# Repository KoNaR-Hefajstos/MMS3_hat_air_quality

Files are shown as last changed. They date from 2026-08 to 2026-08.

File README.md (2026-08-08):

# MMS3 Hat Air Quality
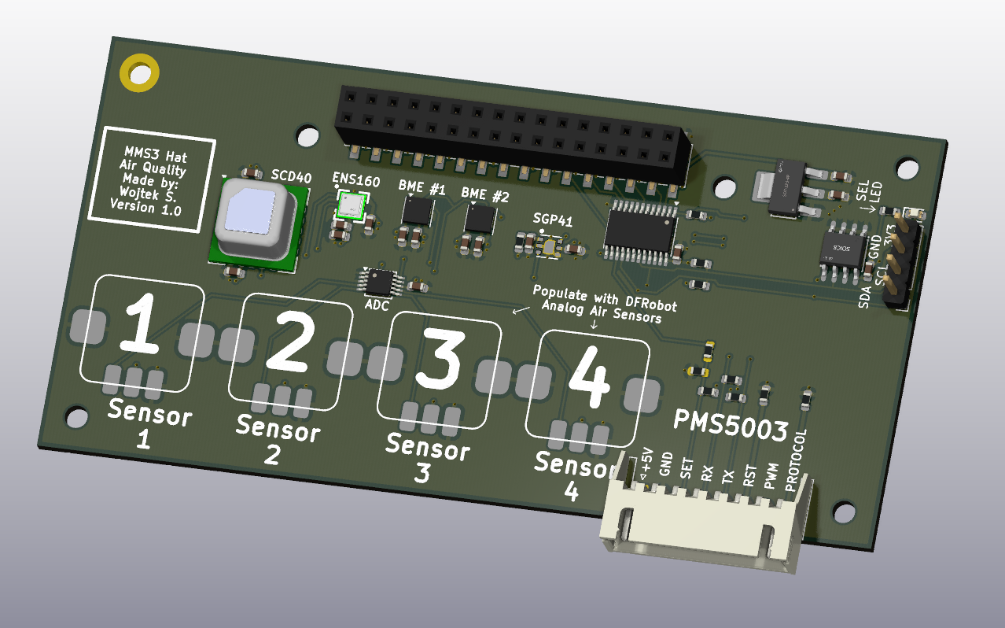
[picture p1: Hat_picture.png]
punkt 1


## Sekcja 1: Dokumentacja Hat'a

### Krótki opis projektu
Hat Air Quality to hat z miejscami na różne czujniki jakości powietrza. Są to 2x BME688 (lub kompatybilne) oraz po jednym PMS5003 (lub kompatybline), SCD40-D-R2, SGP41-D-R4, ENS160-BGLM oraz 4x miejsca na analogowe czujniki DFRobot (np. DFRobot SEN0564).

Dzięki temu potrafi mierzyć temperature, wilgotność, ciśnienie, VOC, IAQ, PM, CO2, NOX oraz wielkości mierzone przez 4x czujniki DFRobot

### Zgodność ze standardem ChainBus

* ✅ Używa złącza ChainBus, nie zmienia jego miejsca ani pinoutu.
* ✅ Używa wyłącznie interfejsów I2C, SPI lub UART i nie inicjuje samodzielnie nowych transmisji (Nie jest master'em I2C albo SPI).
* ✅ Spełnia wymagania mechaniczne standardu (wymiary PCB, rozstaw otworów).
* ❌ Pobiera maksymalny prąd zgodny z ilością na jednego hat'a **-> normalna praca >125mA, potrzeba określić empirycznie**
* ✅ Obsługuje napięcie wejściowe BRD_VIN do wartości 48V.

### Komunikacja i adresowanie

#### Adresacja I2C

| Układ (IC) | Funkcja | Address |
| :--- | :--- | :-----: |
| **BME688 #1** | Czujnik jakości powietrza | `0x76`  |
| **BME688 #2** | Czujnik jakości powietrza | `0x77`  |
| **SCD40-D-R2**  | Czujnik jakości powietrza | `0x62`  |
| **SGP41-D-R4**  | Czujnik jakości powietrza | `0x59`  |
| **ENS160-BGLM** | Czujnik jakości powietrza | `0x52`  |
| **ADS1115IDGS** | Przetwornik ADC | `0x48`  |

#### Magistrala SPI
Brak urządzeń, ale CS może być użyty do włączania/wyłączania PMS5003

#### Magistrala UART
UART jest podłączony bezpośrednio do PMS5003.

| Układ (IC)  | Funkcja | chainbus/multiplexer |
| :--- | :--- | :---: |
| **PMS5003** | Czujnik jakości powietrza | `chainbus` |

### Pinout złączy

| Jn | Co | Jaki pin co robi |
| :--- | :--- | :--- |
| **J101** | Złącze do PMS5003 | **Pin 1: +5V** <br>**Pin 2: GND**<br>**Pin 3: SET** – Wejście włączenia/uśpienia (Stan wysoki = normalna praca, Stan niski = tryb uśpienia)<br>**Pin 4: RX Czujnika**<br>**Pin 5: TX Czujnika** <br>**Pin 6: RST** – Reset modułu (aktywny stan niski - reset po podaniu GND)<br>**Pin 7: PWM** – Wyjście sygnału PWM, NC <br>**Pin 8: PROTOCOL** – Wybór protokołu/trybu pracy czujnika. Ma pulldown 10k |

### Konfiguracja układu (Zworki/Rezystory)

| Co | Jak podłączone | Efekt |
| :--- | :--- | :--- |
| **R101, R102, R104** | Wlutowany R104 | Pin SET zawsze wysoki |
| | Wlutowany  R101, R102 | Pin SET podłączony do pinu CS ChainBus |

### Szczegółowy opis techniczny
Czujniki BME688, SCD40-D-R2, SGP41-D-R4, ENS160-BGLM są bezpośrednio podłączone do magistrali I2C.

Czujniki analogowe DFRobot są podłączone do przetwornika ADC ADS1115IDGS. Kanały przetwornika 0-3 są podłączone do czujników 1-4.

 Czujnik PMS5003 jest bezpośrednio
podłączony do magistrali UART. Jego pin SEL domyślnie jest podciągany do +3.3V przez rezystor R104 (10k), ale można go wylutować
i wlutować R101 R102. Wtedy pin SEL jest bezpośrednio podłączony do pinu CS chainbus oraz ściągany (weak pulldown) do 0V przez R101 (10k).
Jeśli nie potrzebujesz oszczędzać prądu to zalecane jest zostawienie wlutowanego R104.

### Gotowe arkusze hierarchiczne
Brak

---

## Sekcja 2: Specyfikacja standardu ChainBus

### Architektura i łączenie modułów
Standard ChainBus umożliwia modułowe łączenie hatów. Na jednym MMS3 można zamontować pionowo **do 8 hat'ów**. Połączenie realizowane jest poprzez wpięcie złącza męskiego kolejnego hat'a w złącze żeńskie poprzedniego

### Komunikacja i sterowanie
Magistrala ChainBus jest w pełni cyfrowa. Płyta główna nie steruje bezpośrednio sygnałami ogólnego przeznaczenia (GPIO) na poszczególnych hat'ach. Wszelkie operacje (np. obsługa diod LED, odczyt krańcówek, generowanie sygnałów PWM) muszą być realizowane przez dedykowane układy scalone (np. ekspandery portów, sterowniki) komunikujące się przez interfejsy systemowe.

*Przykład:*
`MCU` $\rightarrow$ `Expander GPIO po I2C` $\rightarrow$ `Dioda LED`

Wybór aktywnego modułu realizowany jest przez układ przełącznika magistrali (bus switch) na płycie głównej. Dzięki temu linie I2C, SPI i UART są niezależne dla każdego hat'a (brak konfliktów adresów I2C między różnymi hatami).
* **Identyfikacja:** Każdy moduł powinien posiadać pamięć EEPROM na magistrali I2C w celu identyfikacji płyty przez system - układ M24C64-W skonfigurowany na adres `1010000` przy liniach adresowych A0, A1, A2 zwartych do masy.

### Zasilanie
Złącze ChainBus dostarcza następujące linie zasilania:

| Magistrala zasilania | Napięcie znamionowe | Maksymalny prąd (łączny dla 8 hatów) | Szacowany prąd na jeden hat |
| :--- | :---: | :---: | :---: |
| **5V** | 5.0 V | 1.0 A | 125 mA |
| **12V stby** | 12.0 V | 0.5 A | 65 mA |
| **BRD_VIN** | 12.0 V – 48.0 V | 1.5 A | 185 mA |

*   Komponenty podłączone do linii `BRD_VIN` muszą być przystosowane do pracy z napięciem od 12V do **48 V**.
*   W przypadku zapotrzebowania na wyższą moc, dopuszczalne jest zastosowanie dodatkowego złącza zasilania XT60 (obciążalność do ok. 60 A).

### Wymagania mechaniczne i złącza
* **Wymiary PCB:** Niedozwolona jest zmiana obrysu płytki oraz położenia otworów montażowych, aby zachować kompatybilność mechaniczną.
* **Pozycjonowanie złączy ChainBus:** Położenie złącza standardu 2x16 SMD (raster 2.54 mm) musi być zgodne z szablonem. Złącze żeńskie montowane jest na stronie FRONT, natomiast złącze męskie na stronie BACK.
* **Interfejsy zewnętrzne:** Złącza wejścia/wyjścia (domyślnie standard JST-XH 2.5 mm o obciążalności do 3 A) oraz opcjonalne złącze XT60 powinny być umieszczone przy dolnej krawędzi płytki. Elementy regulacyjne i sygnalizacyjne (potencjometry, przełączniki, diody LED) należy lokalizować przy prawej krawędzi płytki.
* **Komponenty** Wszystkie komponenty powinny być na stronie front płytki żeby nie haczyły o elementy ze wcześniejszego hat'a

---

## Sekcja 3: Licencja, linki i tagi

### Licencjonowanie projektu

*   **PCB:** CERN-OHL-P
*   **Software:** MIT License

[Template](https://github.com/KoNaR-Hefajstos/MMS3_hat_templates/) jest na licencji CC0 1.0 Universal. **Reszta projektu nie jest na tej licencji**

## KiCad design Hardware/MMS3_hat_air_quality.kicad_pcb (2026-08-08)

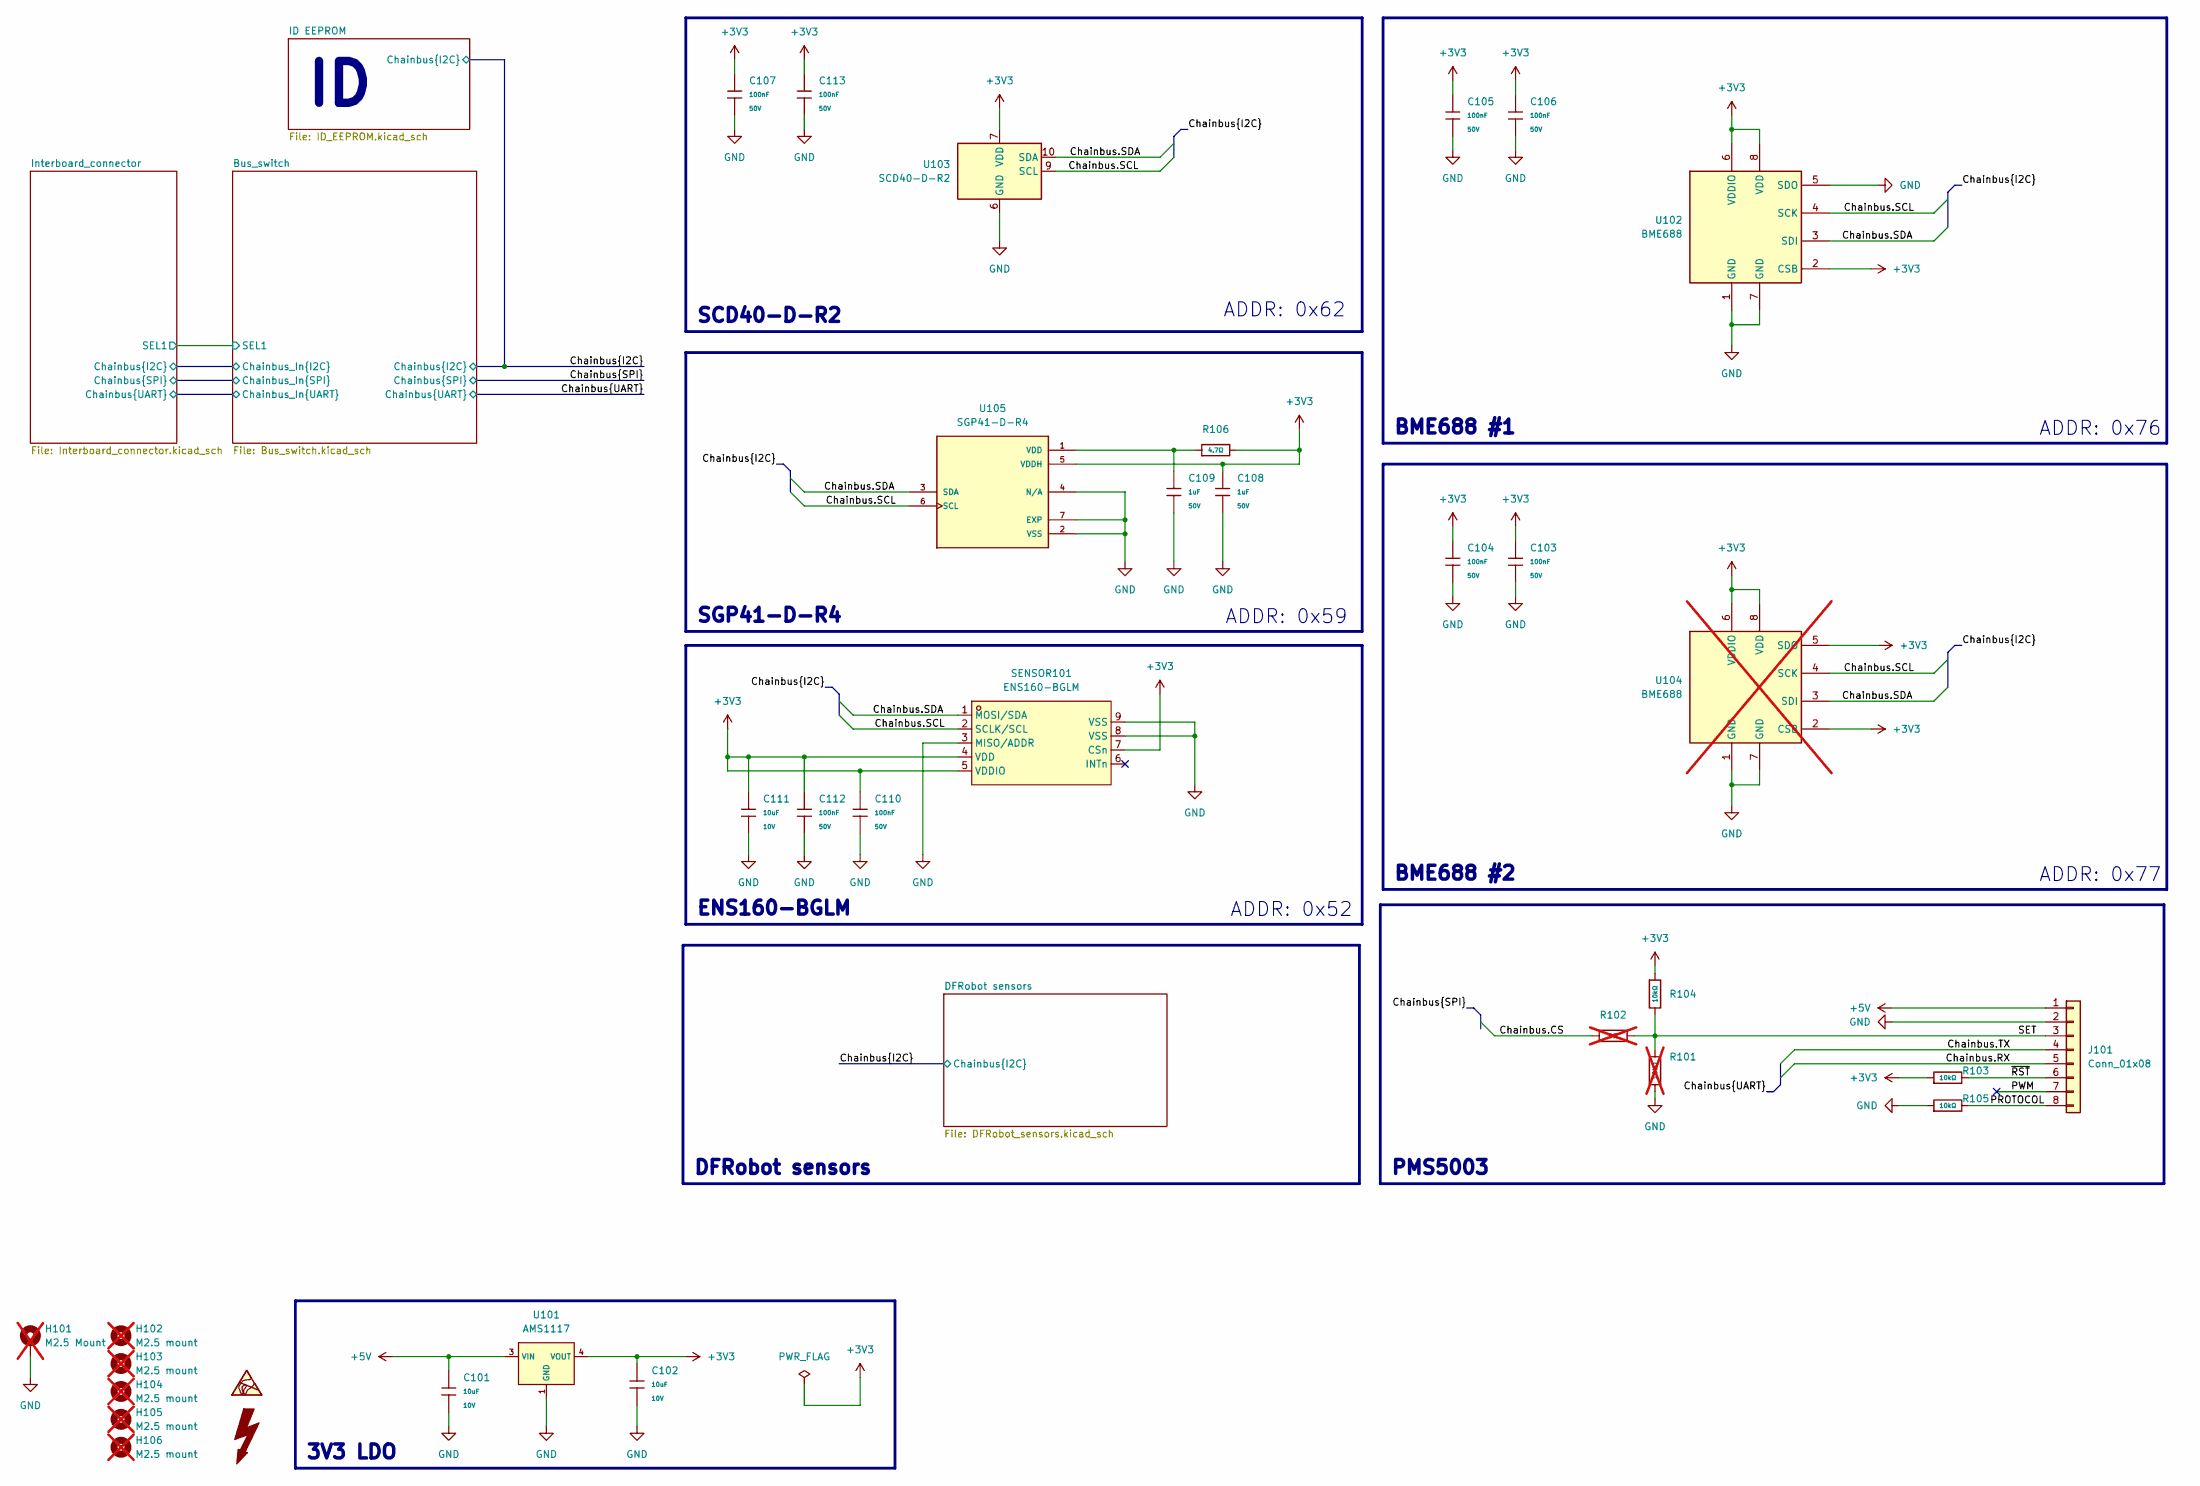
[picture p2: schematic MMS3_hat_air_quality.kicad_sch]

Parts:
C101, C102, C111: 10uF; C_0603; Voltage Rated 10V; Tolerance ±10%; Part CL10A106KP8NNNC; LCSC C19702
C103, C104, C105, C106, C107, C110, C112, C113: 100nF; C_0603; Voltage Rated 50V; Tolerance ±10%; Part CC0603KRX7R9BB104; LCSC C14663
C108, C109: 1uF; C_0603; Voltage Rated 50V; Tolerance ±10%; Part CL10A105KB8NNNC; LCSC C15849
H101: M2.5 Mount; MountingHole_2.7mm_M2.5_DIN965_Pad_TopOnly; not fitted
H102, H103, H104, H105, H106: M2.5 mount; MountingHole_2.7mm_M2.5; not fitted
J101: Conn_01x08; JST_XH_S8B-XH-A-1_1x08_P2.50mm_Horizontal
R101: 10kΩ; R_0603; Overload Voltage (Max) 75V; Tolerance ±1%; Part 0603WAF1002T5E; LCSC C25804; not fitted
R102: 0Ω; R_0603; Overload Voltage (Max) 75V; Tolerance ±1%; Part 0603WAF0000T5E; LCSC C21189; not fitted
R103, R104, R105: 10kΩ; R_0603; Overload Voltage (Max) 75V; Tolerance ±1%; Part 0603WAF1002T5E; LCSC C25804
R106: 4.7Ω; R_0603; Overload Voltage (Max) 75V; Tolerance ±1%; Part 0603WAF470KT5E; LCSC C23164
SENSOR101: ENS160-BGLM; SENSOR-SMD_ENS160-BGLM; MPN ENS160-BGLM; LCSC Part C3659288
U101: AMS1117; SOT-223-3_L6.5-W3.4-P2.30-LS7.0-BR; Output Voltage 3.3V; Dropout Voltage 1.3V@(800mA); Part AMS1117-3.3; LCSC C6186
U102: BME688; Bosch_LGA-8_3x3mm_P0.8mm_ClockwisePinNumbering
U103: SCD40-D-R2; Sensirion_SCD4x-1EP_10.1x10.1mm_P1.25mm_EP4.8x4.8mm; LCSC C3659421
U104: BME688; Bosch_LGA-8_3x3mm_P0.8mm_ClockwisePinNumbering; not fitted
U105: SGP41-D-R4; XDCR_SGP41-D-R4; PARTREV 1.0

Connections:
+3V3: C102.1, C103.1, C104.1, C105.1, C106.1, C107.1, C108.1, C110.1, C111.1, C112.1, C113.1, R103.1, R104.1, R106.2, SENSOR101.4 (VDD), SENSOR101.5 (VDDIO), SENSOR101.7 (CSn), U101.2 (VOUT), U101.4 (VOUT), U102.2 (CSB), U102.6 (VDDIO), U102.8 (VDD), U103.7 (VDD), U103.19 (VDD), U104.2 (CSB), U104.5 (SDO), U104.6 (VDDIO), U104.8 (VDD), U105.5 (VDDH); also elsewhere on the board
+5V: C101.1, J101.1, U101.3 (VIN); also elsewhere on the board
/Chainbus.CS: R102.1; also elsewhere on the board
/Chainbus.RX: J101.5; also elsewhere on the board
/Chainbus.SCL: SENSOR101.2 (SCLK/SCL), U102.4 (SCK), U103.9 (SCL), U104.4 (SCK), U105.6 (SCL); also elsewhere on the board
/Chainbus.SDA: SENSOR101.1 (MOSI/SDA), U102.3 (SDI), U103.10 (SDA), U104.3 (SDI), U105.3 (SDA); also elsewhere on the board
/Chainbus.TX: J101.4; also elsewhere on the board
/PROTOCOL: J101.8, R105.2
/PWM: J101.7
/SET: J101.3, R101.1, R102.2, R104.2
/~RST: J101.6, R103.2
GND: C101.2, C102.2, C103.2, C104.2, C105.2, C106.2, C107.2, C108.2, C109.2, C110.2, C111.2, C112.2, C113.2, H101.1 (1_1), J101.2, R101.2, R105.1, SENSOR101.3 (MISO/ADDR), SENSOR101.8 (VSS), SENSOR101.9 (VSS), U101.1 (GND), U102.1 (GND), U102.5 (SDO), U102.7 (GND), U103.6 (GND), U103.20 (GND), U103.21 (GND), U104.1 (GND), U104.7 (GND), U105.2 (VSS), U105.4 (N/A), U105.7 (EXP); also elsewhere on the board
unnamed: C109.1, R106.1, U105.1 (VDD)

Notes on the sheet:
ADDR: 0x59
BME688 #2
SGP41-D-R4
ADDR: 0x77
PMS5003
ADDR: 0x62
ADDR: 0x52
DFRobot sensors
SCD40-D-R2
ADDR: 0x76
3V3 LDO
BME688 #1
ENS160-BGLM

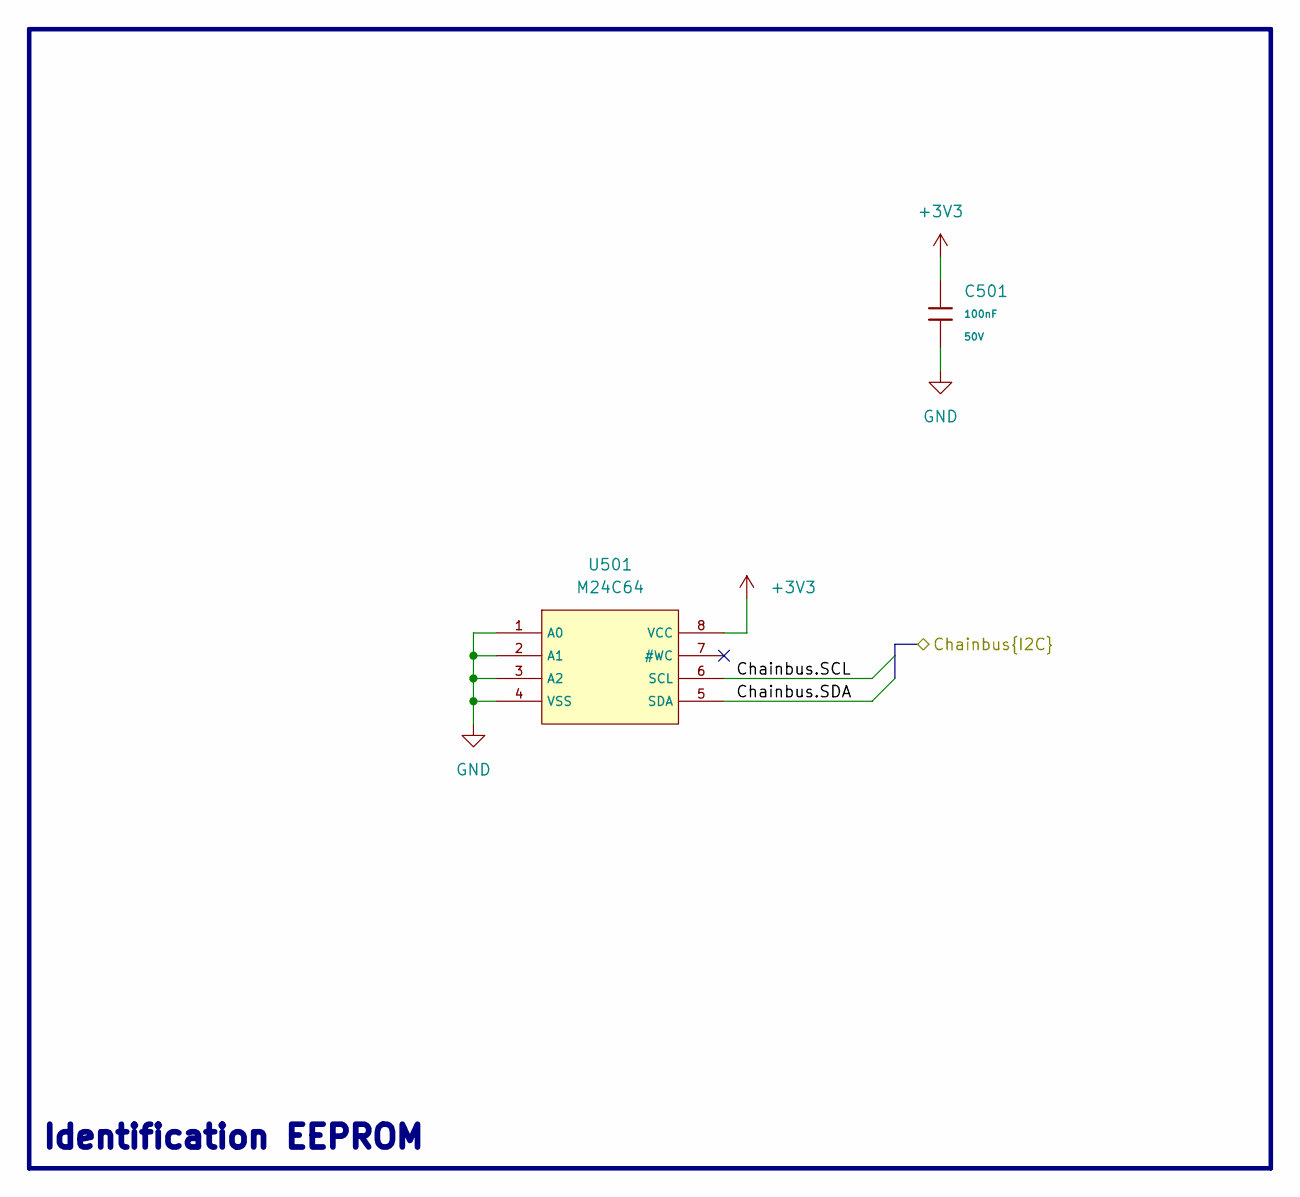
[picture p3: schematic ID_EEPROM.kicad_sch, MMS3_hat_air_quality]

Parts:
C501: 100nF; C_0603; Voltage Rated 50V; Tolerance ±10%; Part CC0603KRX7R9BB104; LCSC C14663
U501: M24C64; SOIC-8_L5.0-W4.0-P1.27-LS6.0-BL; Supply Voltage 1.8V~5.5V; Part M24C64-RMN6TP; LCSC C79988

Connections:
+3V3: C501.1, U501.8 (VCC); also elsewhere on the board
/Chainbus.SCL: U501.6 (SCL); also elsewhere on the board
/Chainbus.SDA: U501.5 (SDA); also elsewhere on the board
GND: C501.2, U501.1 (A0), U501.2 (A1), U501.3 (A2), U501.4 (VSS); also elsewhere on the board

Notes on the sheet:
Identification EEPROM

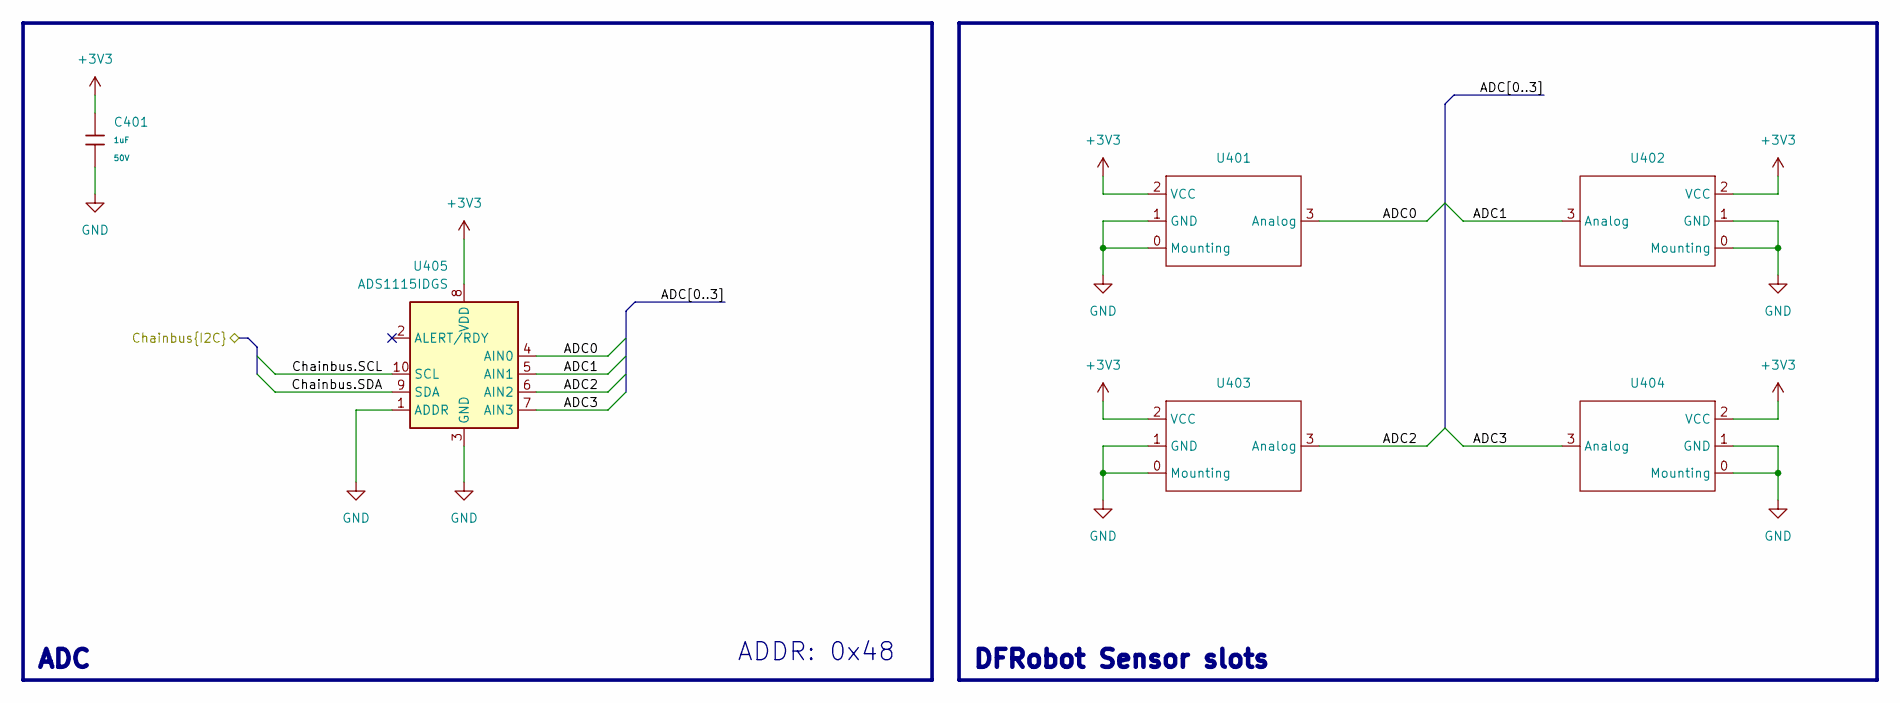
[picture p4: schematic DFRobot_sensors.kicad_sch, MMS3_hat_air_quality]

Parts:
C401: 1uF; C_0603; Voltage Rated 50V; Tolerance ±10%; Part CL10A105KB8NNNC; LCSC C15849
U401, U402, U403, U404: DFRobot
U405: ADS1115IDGS; TSSOP-10_3x3mm_P0.5mm; LCSC C37593

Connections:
+3V3: C401.1, U401.2 (VCC), U402.2 (VCC), U403.2 (VCC), U404.2 (VCC), U405.8 (VDD); also elsewhere on the board
/Chainbus.SCL: U405.10 (SCL); also elsewhere on the board
/Chainbus.SDA: U405.9 (SDA); also elsewhere on the board
/DFRobot sensors/ADC0: U401.3 (Analog), U405.4 (AIN0)
/DFRobot sensors/ADC1: U402.3 (Analog), U405.5 (AIN1)
/DFRobot sensors/ADC2: U403.3 (Analog), U405.6 (AIN2)
/DFRobot sensors/ADC3: U404.3 (Analog), U405.7 (AIN3)
GND: C401.2, U401.0 (Mounting), U401.1 (GND), U402.0 (Mounting), U402.1 (GND), U403.0 (Mounting), U403.1 (GND), U404.0 (Mounting), U404.1 (GND), U405.1 (ADDR), U405.3 (GND); also elsewhere on the board

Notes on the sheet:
ADC
ADDR: 0x48
DFRobot Sensor slots

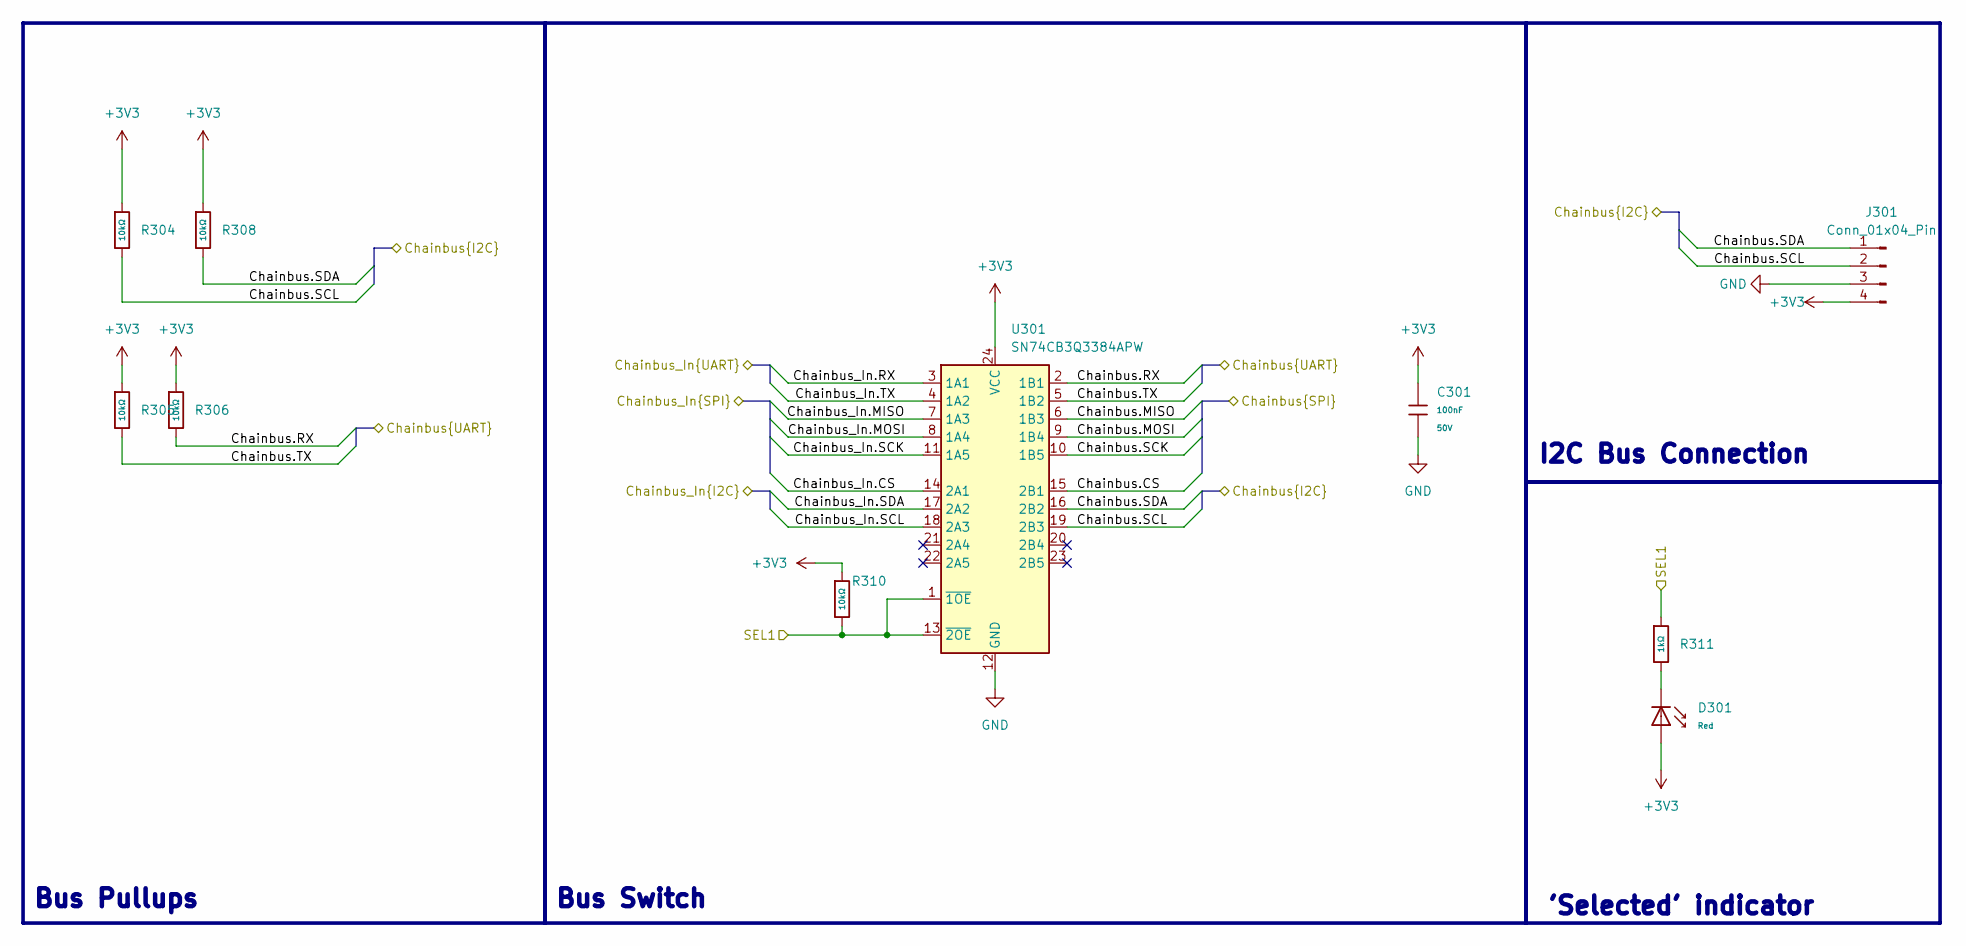
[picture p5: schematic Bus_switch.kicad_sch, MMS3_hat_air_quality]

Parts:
C301: 100nF; C_0603; Voltage Rated 50V; Tolerance ±10%; Part CC0603KRX7R9BB104; LCSC C14663
D301: Red; D_0603; Part KT-0603R; LCSC C2286
J301: Conn_01x04_Pin; PinHeader_1x04_P2.54mm_Vertical
R304, R305, R306, R308, R310: 10kΩ; R_0603; Overload Voltage (Max) 75V; Tolerance ±1%; Part 0603WAF1002T5E; LCSC C25804
R311: 1kΩ; R_0603; Overload Voltage (Max) 75V; Tolerance ±1%; Part 0603WAF1001T5E; LCSC C21190
U301: SN74CB3Q3384APW; TSSOP-24_4.4x7.8mm_P0.65mm; LCSC C469874

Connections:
+3V3: C301.1, D301.2, J301.4, R304.1, R305.1, R306.1, R308.1, R310.1, U301.24 (VCC); also elsewhere on the board
/Bus_switch/Chainbus_In.CS: U301.14 (2A1); also elsewhere on the board
/Bus_switch/Chainbus_In.MISO: U301.7 (1A3); also elsewhere on the board
/Bus_switch/Chainbus_In.MOSI: U301.8 (1A4); also elsewhere on the board
/Bus_switch/Chainbus_In.RX: U301.3 (1A1); also elsewhere on the board
/Bus_switch/Chainbus_In.SCK: U301.11 (1A5); also elsewhere on the board
/Bus_switch/Chainbus_In.SCL: U301.18 (2A3); also elsewhere on the board
/Bus_switch/Chainbus_In.SDA: U301.17 (2A2); also elsewhere on the board
/Bus_switch/Chainbus_In.TX: U301.4 (1A2); also elsewhere on the board
/Bus_switch/SEL1: R310.2, R311.1, U301.1 (~1OE), U301.13 (~2OE); also elsewhere on the board
/Chainbus.CS: U301.15 (2B1); also elsewhere on the board
/Chainbus.MISO: U301.6 (1B3)
/Chainbus.MOSI: U301.9 (1B4)
/Chainbus.RX: R306.2, U301.2 (1B1); also elsewhere on the board
/Chainbus.SCK: U301.10 (1B5)
/Chainbus.SCL: J301.2, R304.2, U301.19 (2B3); also elsewhere on the board
/Chainbus.SDA: J301.1, R308.2, U301.16 (2B2); also elsewhere on the board
/Chainbus.TX: R305.2, U301.5 (1B2); also elsewhere on the board
GND: C301.2, J301.3, U301.12 (GND); also elsewhere on the board
unnamed: D301.1, R311.2

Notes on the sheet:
Bus Switch
'Selected' indicator
Bus Pullups
I2C Bus Connection

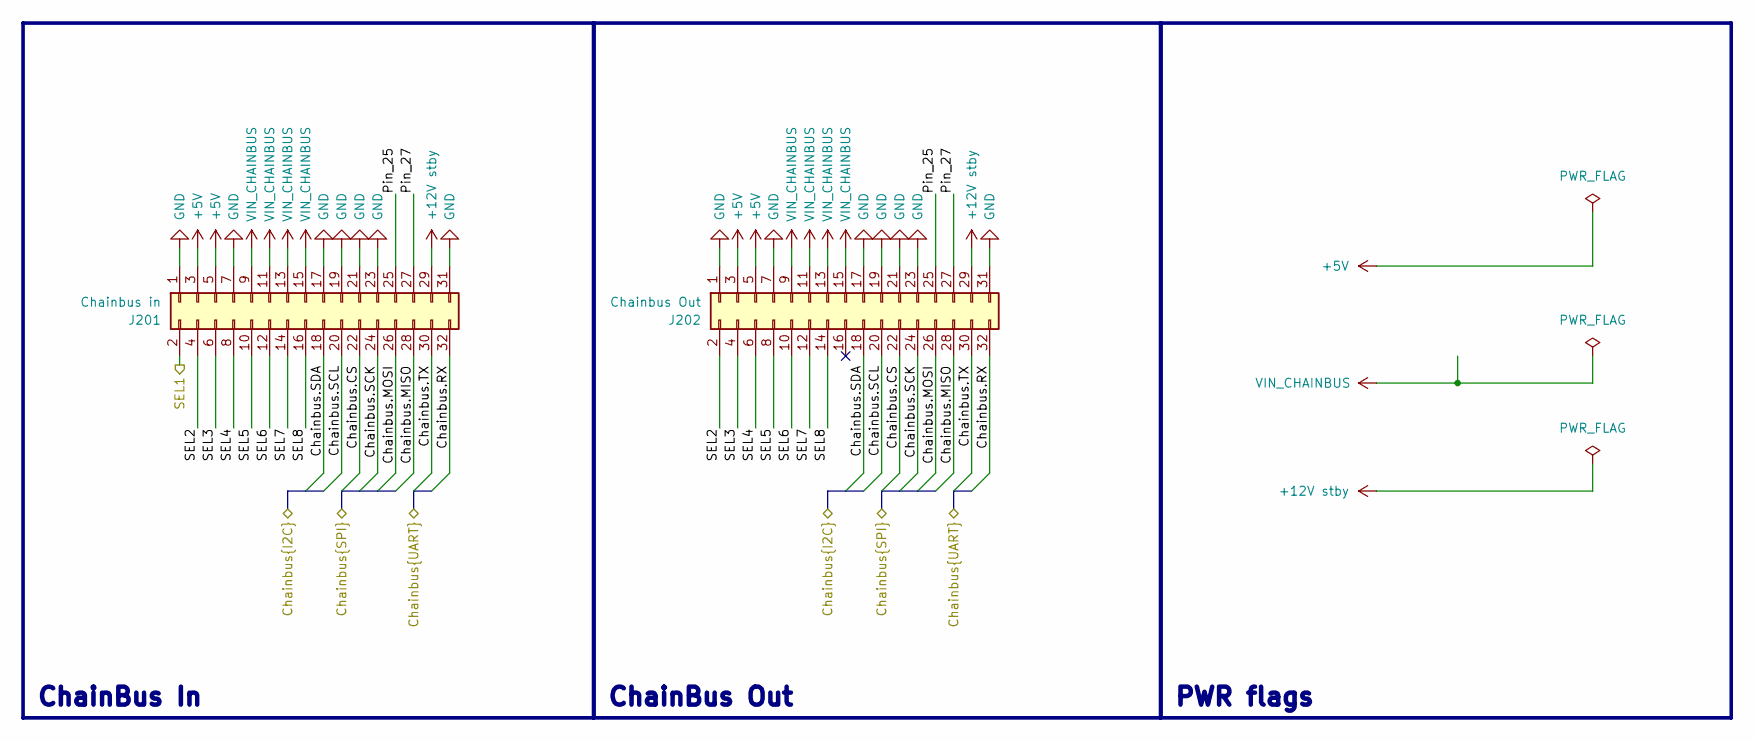
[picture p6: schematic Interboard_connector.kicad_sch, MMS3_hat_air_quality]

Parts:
J201: Chainbus in; PinHeader_2x16_P2.54mm_Vertical_SMD
J202: Chainbus Out; PinSocket_2x16_P2.54mm_Vertical_SMD

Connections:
+5V: J201.3, J201.5, J202.3, J202.5; also elsewhere on the board
+12V stby: J201.29, J202.29
/Bus_switch/Chainbus_In.CS: J201.22, J202.22; also elsewhere on the board
/Bus_switch/Chainbus_In.MISO: J201.28, J202.28; also elsewhere on the board
/Bus_switch/Chainbus_In.MOSI: J201.26, J202.26; also elsewhere on the board
/Bus_switch/Chainbus_In.RX: J201.32, J202.32; also elsewhere on the board
/Bus_switch/Chainbus_In.SCK: J201.24, J202.24; also elsewhere on the board
/Bus_switch/Chainbus_In.SCL: J201.20, J202.20; also elsewhere on the board
/Bus_switch/Chainbus_In.SDA: J201.18, J202.18; also elsewhere on the board
/Bus_switch/Chainbus_In.TX: J201.30, J202.30; also elsewhere on the board
/Bus_switch/SEL1: J201.2; also elsewhere on the board
/Interboard_connector/Pin_25: J201.25, J202.25
/Interboard_connector/Pin_27: J201.27, J202.27
/Interboard_connector/SEL2: J201.4, J202.2
/Interboard_connector/SEL3: J201.6, J202.4
/Interboard_connector/SEL4: J201.8, J202.6
/Interboard_connector/SEL5: J201.10, J202.8
/Interboard_connector/SEL6: J201.12, J202.10
/Interboard_connector/SEL7: J201.14, J202.12
/Interboard_connector/SEL8: J201.16, J202.14
GND: J201.1, J201.7, J201.17, J201.19, J201.21, J201.23, J201.31, J202.1, J202.7, J202.17, J202.19, J202.21, J202.23, J202.31; also elsewhere on the board
VIN_CHAINBUS: J201.9, J201.11, J201.13, J201.15, J202.9, J202.11, J202.13, J202.15

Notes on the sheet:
ChainBus In
PWR flags
ChainBus Out

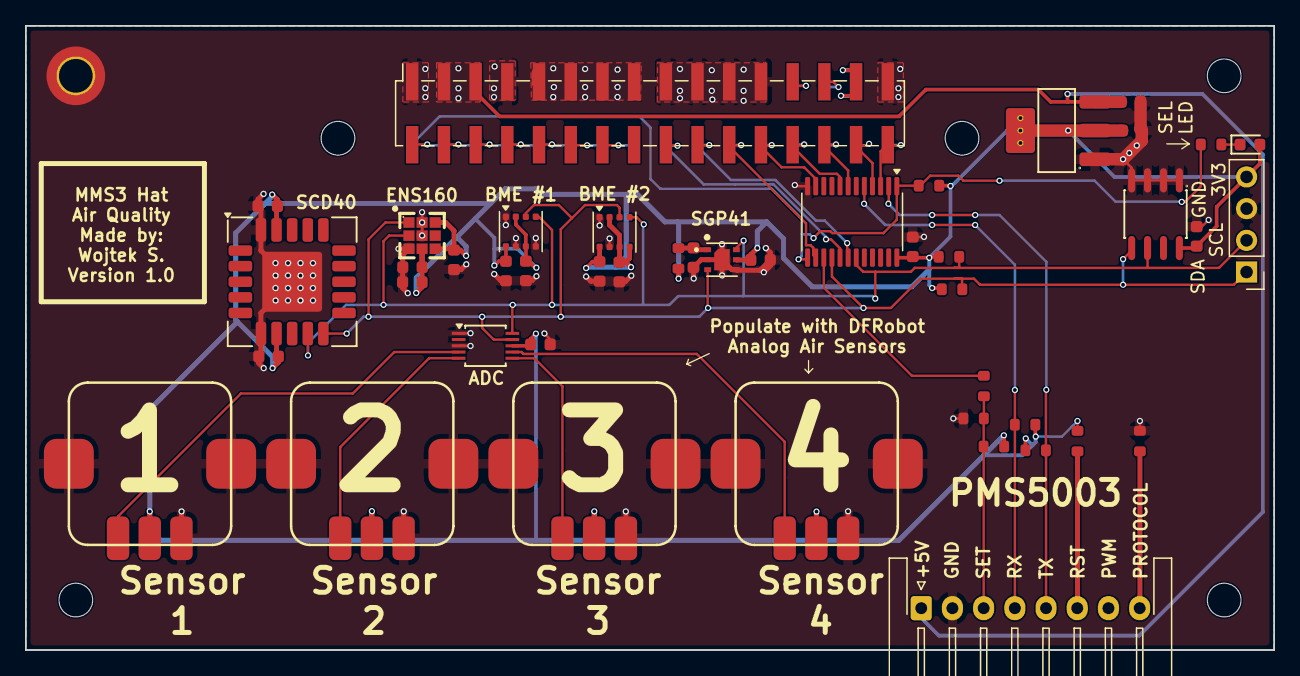
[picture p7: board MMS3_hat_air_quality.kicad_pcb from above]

Board: 2 copper layers, 100.0 x 50.0 mm, 52 parts (1 on the bottom side), 37 nets.

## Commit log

2026-08-07 updated settings to be same as ModuCard BM3
    [Interboard_connector.kicad_sch, MMS3_hat_templates.kicad_pcb]
2026-08-07 finished PCB
    [Bus_switch.kicad_sch, ID_EEPROM.kicad_sch, Interboard_connector.kicad_sch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]
2026-08-07 added photo
    [DFRobot_sensors.kicad_sch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]
2026-08-08 finished readme
    [MMS3_hat_air_quality-CuBottom.gbr, MMS3_hat_air_quality-CuTop.gbr, MMS3_hat_air_quality-EdgeCuts.gbr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]
2026-08-08 added bom
2026-08-08 added I2C Addresses on backsilkscreen
    [MMS3_hat_air_quality-CuBottom.gbr, MMS3_hat_air_quality-CuTop.gbr, MMS3_hat_air_quality-EdgeCuts.gbr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]
